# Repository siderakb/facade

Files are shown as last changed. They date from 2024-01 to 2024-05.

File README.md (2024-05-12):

# Facade60 Keyboard



- 60% mechanical keyboard kit, 2U LShift layout
- 65 keys, Cherry MX style hot-swappable
- Gasket mount
- CNC Aluminum top case
- MJF Nylon bottom case
- USB & RP2040 MCU daughterboard
- [QMK](https://qmk.fm/) and [Vial](https://get.vial.today/) support

[Demo video](https://youtu.be/Ful9dqWGcHk)

## Structure



- Top case
- Gaskets
- Plate
- Gaskets
- Optional sound absorbing foam
- PCB
- Optional case foam
- Bottom case
- Weight

## PCB



Daughterboard PCBA available.

### Board Characteristics

- Copper layer count: 2
- Board thickness: 1.6 mm
- Board overall dimensions
    - Main board: 285 mm x 99.1 mm
    - Daughterboard: 29.25 mm x 43.75 mm
- Min track/spacing: 0.15 mm / 0.15 mm
- Min hole diameter: 0.3 mm
- Castellated pads: No
- Edge card connectors: No
- Plated board edge: No

## Case

CAD files: [onshape](https://cad.onshape.com/documents/bbbe7399d3367f05c1e650e9/w/14fd774c6821c6187949e29b/e/877617ade201dbca93eed7b8)

### Screw

- 6* M2.5x10~12, OD < 5mm, for case
- 4* M2x2, 90° flat head, for weight
- 4* M2.5x3~5, OD <3.5mm, for PCB

## Firmware

[Vial-QMK](https://github.com/siderakb/vial-qmk/tree/siderakb/main/keyboards/siderakb/facade) (*siderakb/main* branch)

## License

Hardware available under the [CERN-OHL-P v2](/LICENSE) permissive license.

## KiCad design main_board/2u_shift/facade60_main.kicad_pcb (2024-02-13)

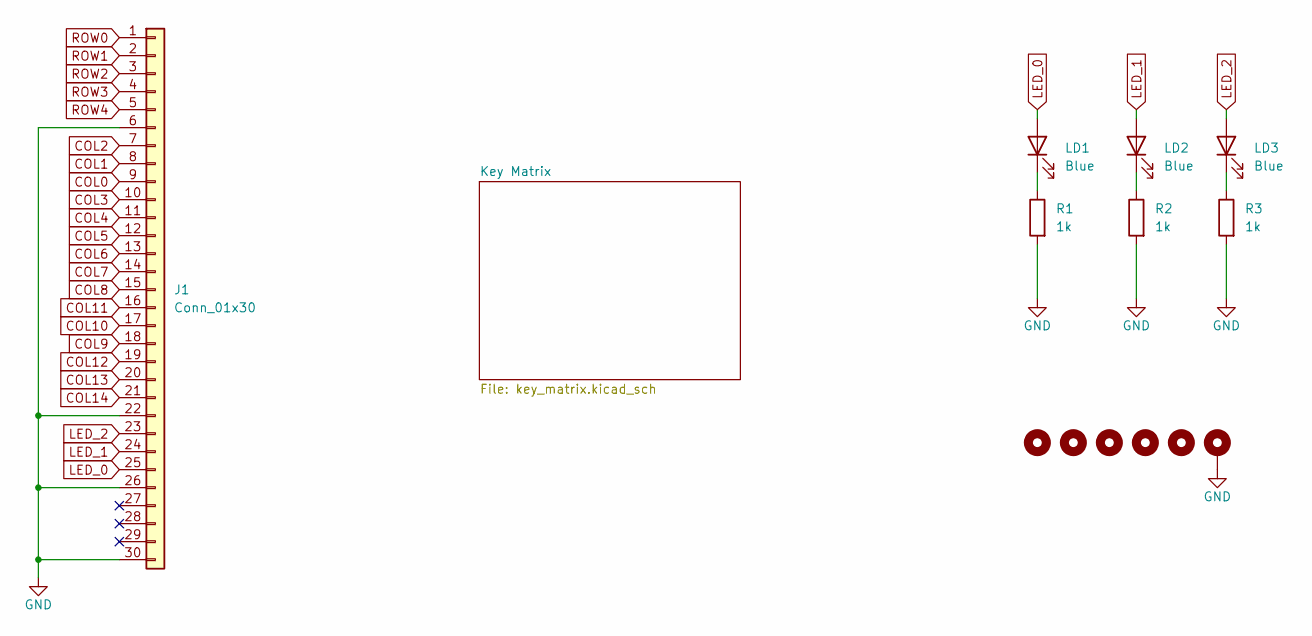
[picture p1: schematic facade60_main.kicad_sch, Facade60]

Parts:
H5, H6: MountingHole; MountingHole-C
H8, H9, H10: MountingHole_Pad; MountingHole-D
H11: MountingHole_Pad; MountingHole-B
J1: Conn_01x30; TE_3-1734839-0_1x30-1MP_P0.5mm_Horizontal
LD1, LD2, LD3: Blue; LED_0603_1608Metric; MFR. Part # 19-217/GHC-YR1S2/3T; LCSC C72043
R1, R2, R3: 1k; R_0603_1608Metric; MFR. Part # 0402WGF1001TCE; LCSC C11702

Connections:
COL0: J1.9; also elsewhere on the board
COL1: J1.8; also elsewhere on the board
COL2: J1.7; also elsewhere on the board
COL3: J1.10; also elsewhere on the board
COL4: J1.11; also elsewhere on the board
COL5: J1.12; also elsewhere on the board
COL6: J1.13; also elsewhere on the board
COL7: J1.14; also elsewhere on the board
COL8: J1.15; also elsewhere on the board
COL9: J1.18; also elsewhere on the board
COL10: J1.17; also elsewhere on the board
COL11: J1.16; also elsewhere on the board
COL12: J1.19; also elsewhere on the board
COL13: J1.20; also elsewhere on the board
COL14: J1.21; also elsewhere on the board
GND: H11.1, J1.6, J1.22, J1.26, J1.30, R1.2, R2.2, R3.2
LED_0: J1.25, LD1.2 (A)
LED_1: J1.24, LD2.2 (A)
LED_2: J1.23, LD3.2 (A)
unnamed: LD1.1 (K), R1.1
unnamed: LD2.1 (K), R2.1
unnamed: LD3.1 (K), R3.1
ROW0: J1.1; also elsewhere on the board
ROW1: J1.2; also elsewhere on the board
ROW2: J1.3; also elsewhere on the board
ROW3: J1.4; also elsewhere on the board
ROW4: J1.5; also elsewhere on the board

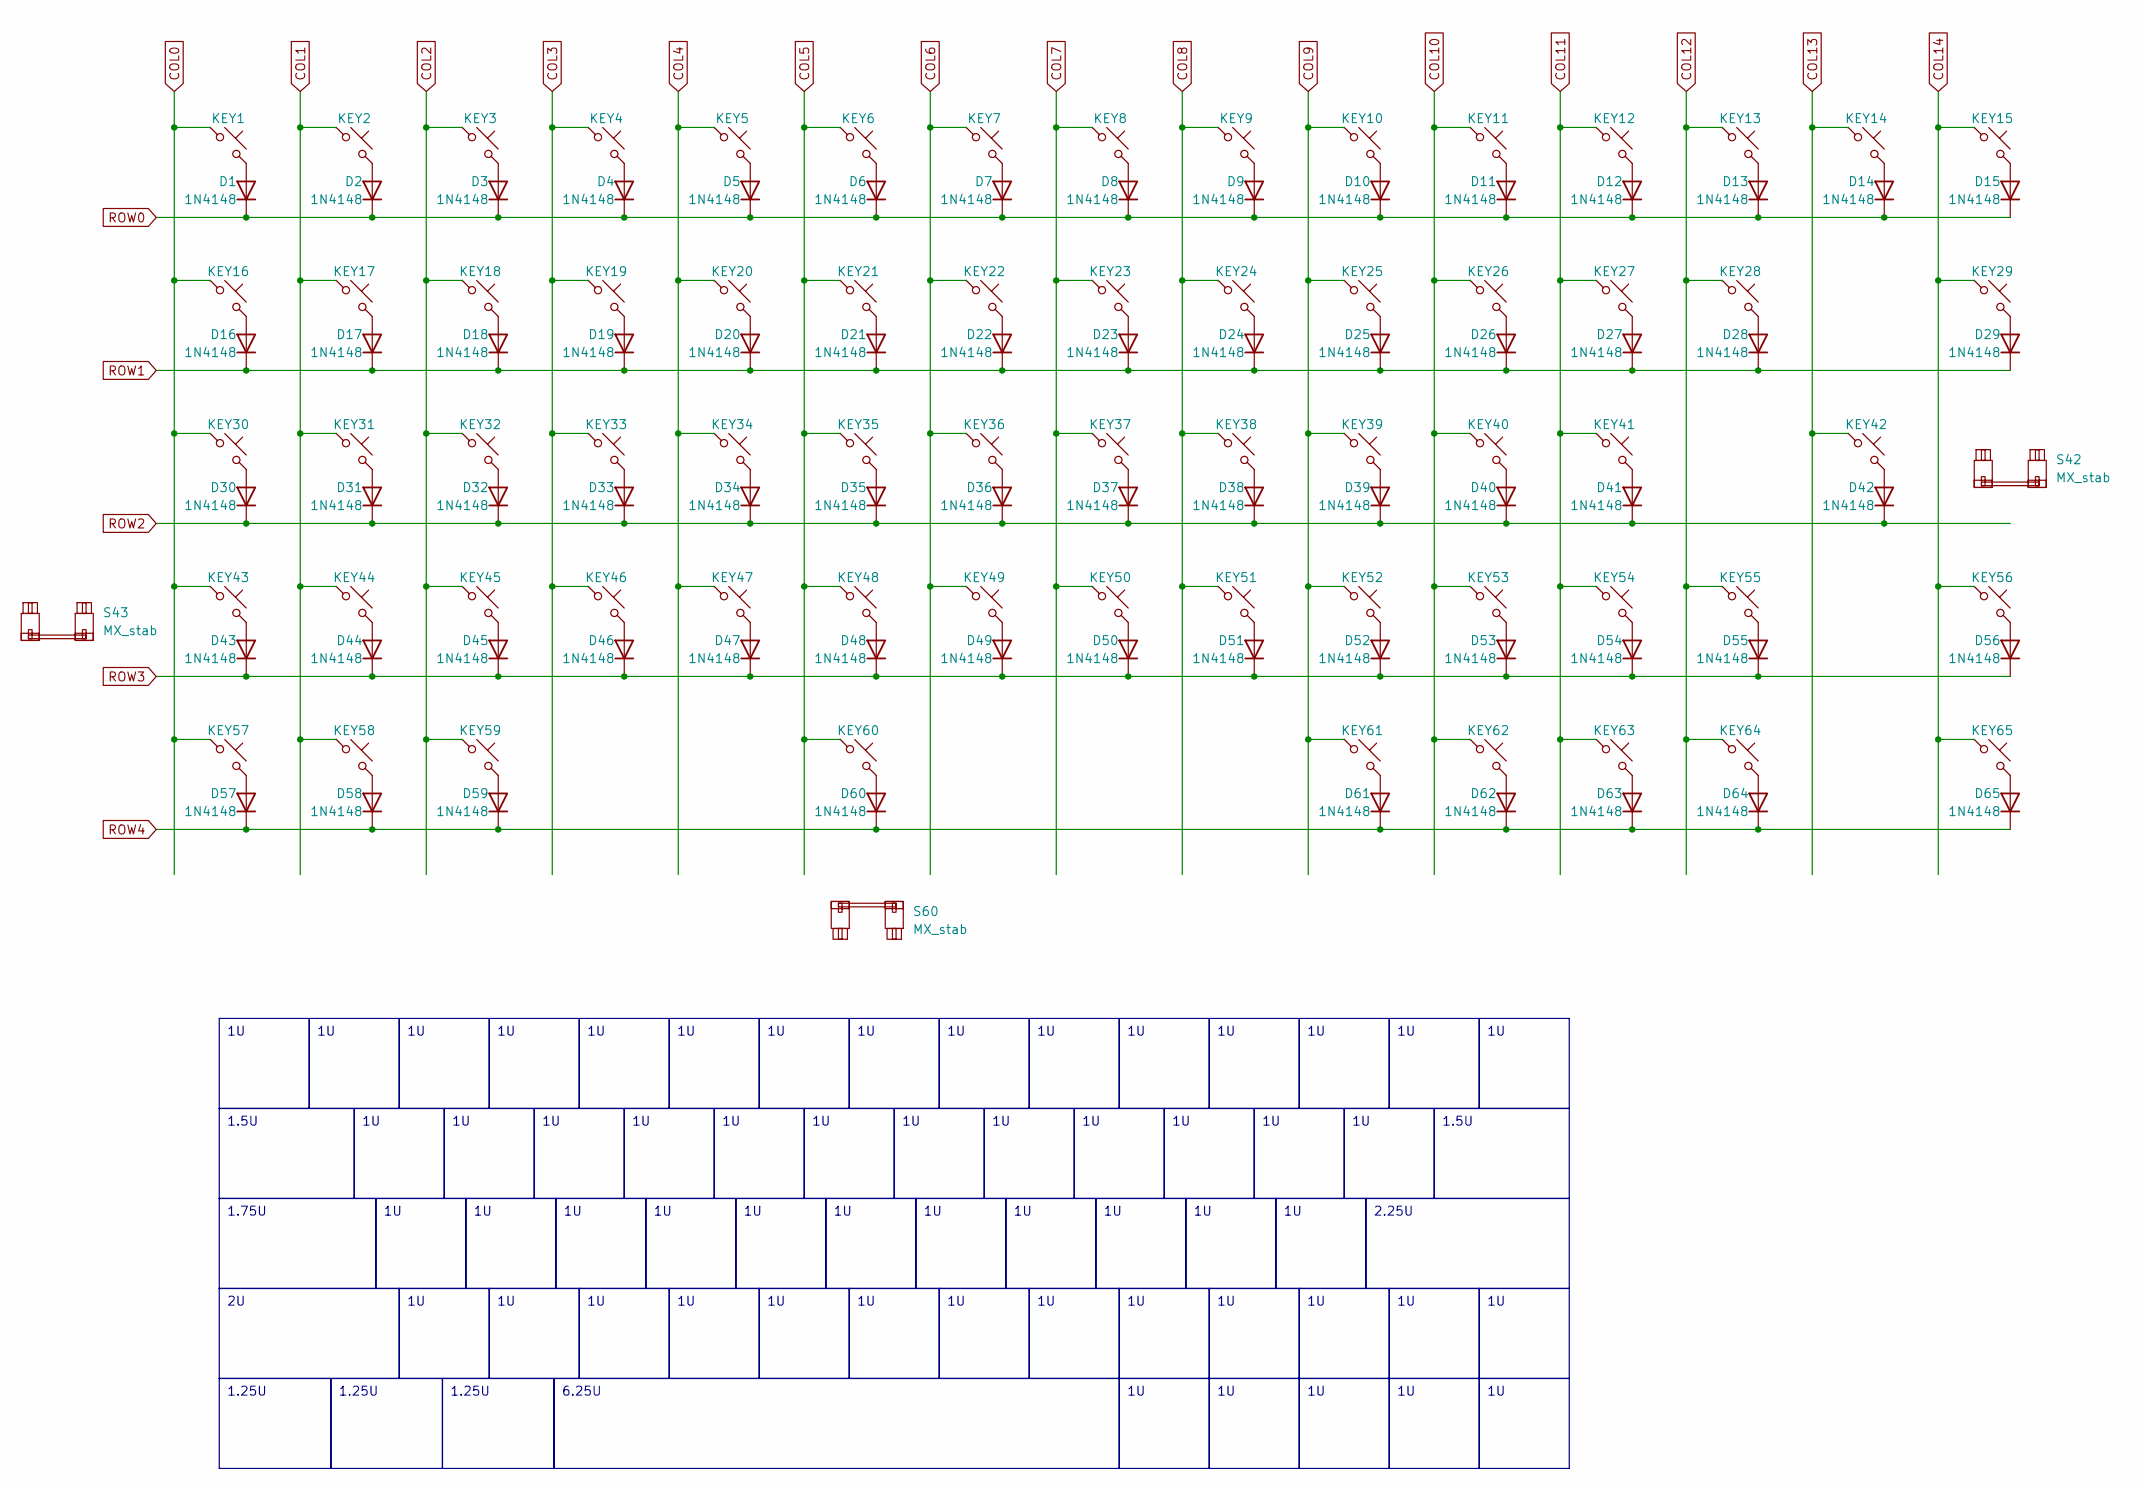
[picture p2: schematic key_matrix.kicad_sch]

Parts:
D1, D2, D3, D4, D5, D6, D7, D8, D9, D10, D11, D12, D13, D14, D15, D16, D17, D18, D19, D20, D21, D22, D23, D24, D25, D26, D27, D28, D29, D30, D31, D32, D33, D34, D35, D36, D37, D38, D39, D40, D41, D42, D43, D44, D45, D46, D47, D48, D49, D50, D51, D52, D53, D54, D55, D56, D57, D58, D59, D60, D61, D62, D63, D64, D65: 1N4148; D_SOD-323_HandSoldering; MFR. Part # 1N4148W; LCSC C81598
KEY1, KEY2, KEY3, KEY4, KEY5, KEY6, KEY7, KEY8, KEY9, KEY10, KEY11, KEY12, KEY13, KEY14, KEY15, KEY16, KEY17, KEY18, KEY19, KEY20, KEY21, KEY22, KEY23, KEY24, KEY25, KEY26, KEY27, KEY28, KEY29, KEY30, KEY31, KEY32, KEY33, KEY34, KEY35, KEY36, KEY37, KEY38, KEY39, KEY40, KEY41, KEY42, KEY43, KEY44, KEY45, KEY46, KEY47, KEY48, KEY49, KEY50, KEY51, KEY52, KEY53, KEY54, KEY55, KEY56, KEY57, KEY58, KEY59, KEY60, KEY61, KEY62, KEY63, KEY64, KEY65: SW_Push_45deg; SW_MX_HotSwap_PTH_nSilk
S42: MX_stab; STAB_MX_2.25u
S43: MX_stab; STAB_MX_2u
S60: MX_stab; STAB_MX_6.25u

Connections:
COL0: KEY1.1, KEY16.1, KEY30.1, KEY43.1, KEY57.1; also elsewhere on the board
COL1: KEY2.1, KEY17.1, KEY31.1, KEY44.1, KEY58.1; also elsewhere on the board
COL2: KEY3.1, KEY18.1, KEY32.1, KEY45.1, KEY59.1; also elsewhere on the board
COL3: KEY4.1, KEY19.1, KEY33.1, KEY46.1; also elsewhere on the board
COL4: KEY5.1, KEY20.1, KEY34.1, KEY47.1; also elsewhere on the board
COL5: KEY6.1, KEY21.1, KEY35.1, KEY48.1, KEY60.1; also elsewhere on the board
COL6: KEY7.1, KEY22.1, KEY36.1, KEY49.1; also elsewhere on the board
COL7: KEY8.1, KEY23.1, KEY37.1, KEY50.1; also elsewhere on the board
COL8: KEY9.1, KEY24.1, KEY38.1, KEY51.1; also elsewhere on the board
COL9: KEY10.1, KEY25.1, KEY39.1, KEY52.1, KEY61.1; also elsewhere on the board
COL10: KEY11.1, KEY26.1, KEY40.1, KEY53.1, KEY62.1; also elsewhere on the board
COL11: KEY12.1, KEY27.1, KEY41.1, KEY54.1, KEY63.1; also elsewhere on the board
COL12: KEY13.1, KEY28.1, KEY55.1, KEY64.1; also elsewhere on the board
COL13: KEY14.1, KEY42.1; also elsewhere on the board
COL14: KEY15.1, KEY29.1, KEY56.1, KEY65.1; also elsewhere on the board
unnamed: D1.2 (A), KEY1.2
unnamed: D2.2 (A), KEY2.2
unnamed: D3.2 (A), KEY3.2
unnamed: D4.2 (A), KEY4.2
unnamed: D5.2 (A), KEY5.2
unnamed: D6.2 (A), KEY6.2
unnamed: D7.2 (A), KEY7.2
unnamed: D8.2 (A), KEY8.2
unnamed: D9.2 (A), KEY9.2
unnamed: D10.2 (A), KEY10.2
unnamed: D11.2 (A), KEY11.2
unnamed: D12.2 (A), KEY12.2
unnamed: D13.2 (A), KEY13.2
unnamed: D14.2 (A), KEY14.2
unnamed: D15.2 (A), KEY15.2
unnamed: D16.2 (A), KEY16.2
unnamed: D17.2 (A), KEY17.2
unnamed: D18.2 (A), KEY18.2
unnamed: D19.2 (A), KEY19.2
unnamed: D20.2 (A), KEY20.2
unnamed: D21.2 (A), KEY21.2
unnamed: D22.2 (A), KEY22.2
unnamed: D23.2 (A), KEY23.2
unnamed: D24.2 (A), KEY24.2
unnamed: D25.2 (A), KEY25.2
unnamed: D26.2 (A), KEY26.2
unnamed: D27.2 (A), KEY27.2
unnamed: D28.2 (A), KEY28.2
unnamed: D29.2 (A), KEY29.2
unnamed: D30.2 (A), KEY30.2
unnamed: D31.2 (A), KEY31.2
unnamed: D32.2 (A), KEY32.2
unnamed: D33.2 (A), KEY33.2
unnamed: D34.2 (A), KEY34.2
unnamed: D35.2 (A), KEY35.2
unnamed: D36.2 (A), KEY36.2
unnamed: D37.2 (A), KEY37.2
unnamed: D38.2 (A), KEY38.2
unnamed: D39.2 (A), KEY39.2
unnamed: D40.2 (A), KEY40.2
unnamed: D41.2 (A), KEY41.2
unnamed: D42.2 (A), KEY42.2
unnamed: D43.2 (A), KEY43.2
unnamed: D44.2 (A), KEY44.2
unnamed: D45.2 (A), KEY45.2
unnamed: D46.2 (A), KEY46.2
unnamed: D47.2 (A), KEY47.2
unnamed: D48.2 (A), KEY48.2
unnamed: D49.2 (A), KEY49.2
unnamed: D50.2 (A), KEY50.2
unnamed: D51.2 (A), KEY51.2
unnamed: D52.2 (A), KEY52.2
unnamed: D53.2 (A), KEY53.2
unnamed: D54.2 (A), KEY54.2
unnamed: D55.2 (A), KEY55.2
unnamed: D56.2 (A), KEY56.2
unnamed: D57.2 (A), KEY57.2
unnamed: D58.2 (A), KEY58.2
unnamed: D59.2 (A), KEY59.2
unnamed: D60.2 (A), KEY60.2
unnamed: D61.2 (A), KEY61.2
unnamed: D62.2 (A), KEY62.2
unnamed: D63.2 (A), KEY63.2
unnamed: D64.2 (A), KEY64.2
unnamed: D65.2 (A), KEY65.2
ROW0: D1.1 (K), D2.1 (K), D3.1 (K), D4.1 (K), D5.1 (K), D6.1 (K), D7.1 (K), D8.1 (K), D9.1 (K), D10.1 (K), D11.1 (K), D12.1 (K), D13.1 (K), D14.1 (K), D15.1 (K); also elsewhere on the board
ROW1: D16.1 (K), D17.1 (K), D18.1 (K), D19.1 (K), D20.1 (K), D21.1 (K), D22.1 (K), D23.1 (K), D24.1 (K), D25.1 (K), D26.1 (K), D27.1 (K), D28.1 (K), D29.1 (K); also elsewhere on the board
ROW2: D30.1 (K), D31.1 (K), D32.1 (K), D33.1 (K), D34.1 (K), D35.1 (K), D36.1 (K), D37.1 (K), D38.1 (K), D39.1 (K), D40.1 (K), D41.1 (K), D42.1 (K); also elsewhere on the board
ROW3: D43.1 (K), D44.1 (K), D45.1 (K), D46.1 (K), D47.1 (K), D48.1 (K), D49.1 (K), D50.1 (K), D51.1 (K), D52.1 (K), D53.1 (K), D54.1 (K), D55.1 (K), D56.1 (K); also elsewhere on the board
ROW4: D57.1 (K), D58.1 (K), D59.1 (K), D60.1 (K), D61.1 (K), D62.1 (K), D63.1 (K), D64.1 (K), D65.1 (K); also elsewhere on the board

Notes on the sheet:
1.5U
2.25U
1.25U
6.25U
1.75U

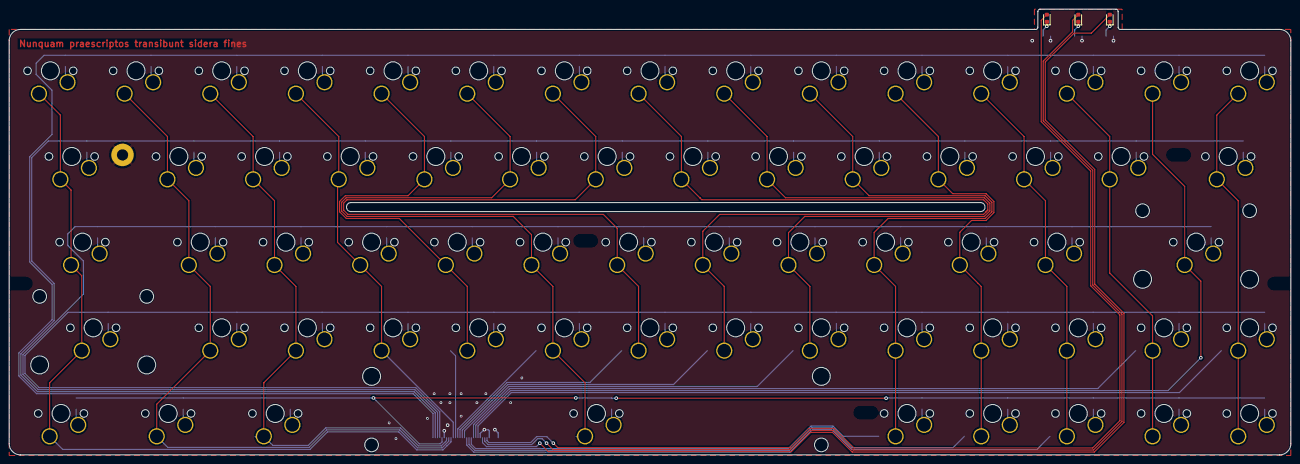
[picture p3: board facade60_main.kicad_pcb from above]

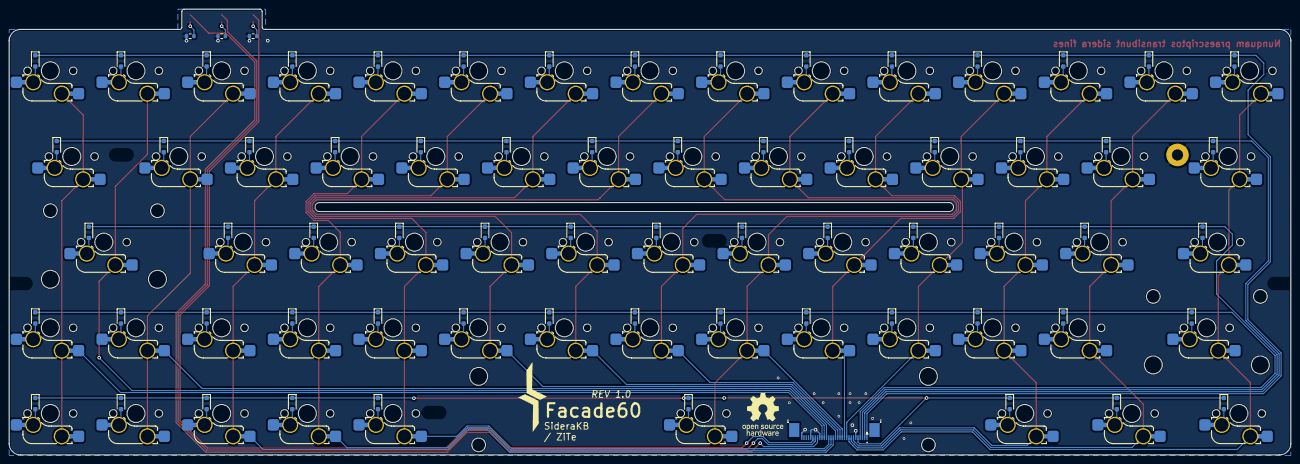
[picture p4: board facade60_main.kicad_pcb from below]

Board: 2 copper layers, 285.0 x 99.1 mm, 146 parts (69 on the bottom side), 92 nets.

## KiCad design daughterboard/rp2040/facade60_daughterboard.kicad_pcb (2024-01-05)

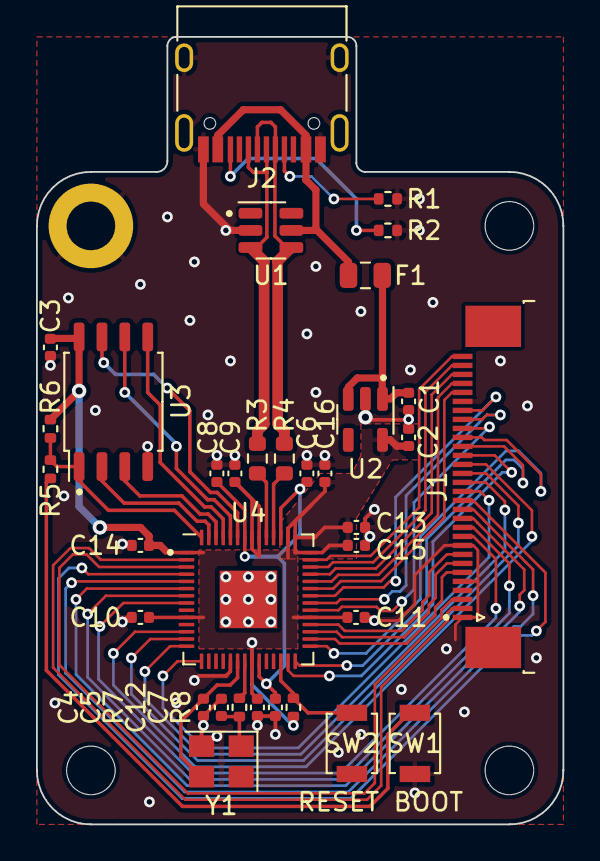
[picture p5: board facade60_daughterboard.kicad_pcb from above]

Board: 2 copper layers, 29.2 x 43.8 mm, 38 parts (0 on the bottom side), 47 nets.

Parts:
C1, C2, C8, C16: 1uF; C_0402_1005Metric
C3, C6, C7, C9, C10, C11, C12, C13, C14, C15: 100nF; C_0402_1005Metric
C4, C5: 20pF; C_0402_1005Metric
F1: 500mA, 6V; Fuse_0805_2012Metric
H1: MountingHole; MountingHole_2.7mm_M2.5_DIN965_Pad
H2, H3, H4: MountingHole; MountingHole_2.7mm_M2.5
J1: Conn_01x30; TE_3-1734839-0_1x30-1MP_P0.5mm_Horizontal
J2: USB_C_Receptacle_USB2.0; USB_C_Receptacle_HRO_TYPE-C-31-M-12
R1, R2: 5.1k; R_0402_1005Metric
R3, R4: 27; R_0603_1608Metric
R5, R7: 1k; R_0402_1005Metric
R6, R8: 10k; R_0402_1005Metric
SW1: BOOT; SW_SPST_B3U-1000P
SW2: RESET; SW_SPST_B3U-1000P
U1: SRV05-4; SOT-23-6
U2: RT9013-33GB; SOT-23-5
U3: W25Q128JVS; SOIC-8_5.23x5.23mm_P1.27mm
U4: RP2040; QFN-56-1EP_7x7mm_P0.4mm_EP3.2x3.2mm
Y1: 12MHz; Crystal_SMD_3225-4Pin_3.2x2.5mm

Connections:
+1V1: C6.1, C7.1, C8.1, U4.23 (DVDD), U4.45 (VREG_VOUT), U4.50 (DVDD)
+3V3: C2.1, C3.1, C9.1, C10.1, C11.1, C12.1, C13.1, C14.1, C15.1, C16.1, R6.1, R8.1, U2.5 (VOUT), U3.8 (VCC), U4.1 (IOVDD), U4.10 (IOVDD), U4.22 (IOVDD), U4.33 (IOVDD), U4.42 (IOVDD), U4.43 (ADC_AVDD), U4.44 (VREG_IN), U4.48 (USB_VDD), U4.49 (IOVDD)
+5V: C1.1, F1.2, U2.1 (VIN), U2.3 (EN)
/MCU/BOOT: R5.1, SW1.2
/MCU/QSPI_D0: U3.5 (DI(IO0)), U4.53 (QSPI_SD0)
/MCU/QSPI_D1: U3.2 (DO(IO1)), U4.55 (QSPI_SD1)
/MCU/QSPI_D2: U3.3 (IO2), U4.54 (QSPI_SD2)
/MCU/QSPI_D3: U3.7 (IO3), U4.51 (QSPI_SD3)
/MCU/QSPI_SCLK: U3.6 (CLK), U4.52 (QSPI_SCLK)
/MCU/QSPI_SS: R5.2, R6.2, U3.1 (~CS), U4.56 (QSPI_SS)
/MCU/~RESET: R8.2, SW2.2, U4.26 (RUN)
COL0: J1.22, U4.34 (GPIO22)
COL1: J1.23, U4.35 (GPIO23)
COL2: J1.24, U4.36 (GPIO24)
COL3: J1.21, U4.29 (GPIO18)
COL4: J1.20, U4.28 (GPIO17)
COL5: J1.19, U4.27 (GPIO16)
COL6: J1.18, U4.12 (GPIO9)
COL7: J1.17, U4.13 (GPIO10)
COL8: J1.16, U4.14 (GPIO11)
COL9: J1.13, U4.5 (GPIO3)
COL10: J1.14, U4.4 (GPIO2)
COL11: J1.15, U4.15 (GPIO12)
COL12: J1.12, U4.6 (GPIO4)
COL13: J1.11, U4.7 (GPIO5)
COL14: J1.10, U4.8 (GPIO6)
EC_A: J1.3, U4.3 (GPIO1)
EC_B: J1.2, U4.2 (GPIO0)
GND: C1.2, C2.2, C3.2, C4.1, C5.1, C6.2, C7.2, C8.2, C9.2, C10.2, C11.2, C12.2, C13.2, C14.2, C15.2, C16.2, H1.1, J1.1, J1.5, J1.9, J1.25, J2.A1 (GND), J2.A12 (GND), J2.B1 (GND), J2.B12 (GND), J2.S1 (SHIELD), R1.2, R2.2, SW1.1, SW2.1, U1.2 (VN), U2.2 (GND), U3.4 (GND), U4.19 (TESTEN), U4.57 (GND), Y1.2, Y1.4
LED_0: J1.6, U4.30 (GPIO19)
LED_1: J1.7, U4.31 (GPIO20)
LED_2: J1.8, U4.32 (GPIO21)
unnamed: C5.2, R7.1, Y1.1
unnamed: J2.A5 (CC1), R1.1
unnamed: J2.B5 (CC2), R2.1
unnamed: R4.2, U4.46 (USB_DM)
unnamed: R3.2, U4.47 (USB_DP)
unnamed: C4.2, U4.20 (XIN), Y1.3
unnamed: R7.2, U4.21 (XOUT)
ROW0: J1.30, U4.41 (GPIO29_ADC3)
ROW1: J1.29, U4.40 (GPIO28_ADC2)
ROW2: J1.28, U4.39 (GPIO27_ADC1)
ROW3: J1.27, U4.38 (GPIO26_ADC0)
ROW4: J1.26, U4.37 (GPIO25)
USB_D+: J2.A6 (D+), J2.B6 (D+), R3.1, U1.3 (IO2)
USB_D-: J2.A7 (D-), J2.B7 (D-), R4.1, U1.4 (IO3)
VBUS: F1.1, J2.A4 (VBUS), J2.A9 (VBUS), J2.B4 (VBUS), J2.B9 (VBUS), U1.5 (VP)

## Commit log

2024-01-03 Add KiCad project
    [facade60_daughterboard.kicad_pcb, facade60_daughterboard.kicad_sch, facade60_main.kicad_pcb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]
2024-01-05 Replace R1 & R2 to 0402
    [facade60_daughterboard.kicad_pcb, facade60_daughterboard.kicad_sch, facade60_main.kicad_pcb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]
2024-02-13 Update KLE files
    [facade60_main.kicad_pcb]

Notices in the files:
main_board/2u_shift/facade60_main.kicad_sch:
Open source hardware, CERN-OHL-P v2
